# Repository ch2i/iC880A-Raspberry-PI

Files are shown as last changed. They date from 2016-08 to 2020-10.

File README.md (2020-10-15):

# Raspberry PI iC880A and LinkLab Lora Gateway Shield

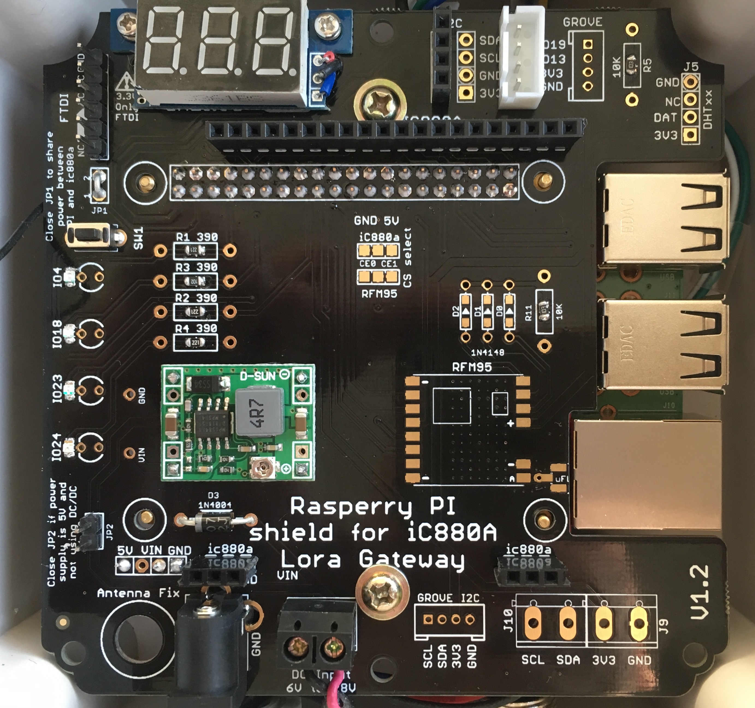
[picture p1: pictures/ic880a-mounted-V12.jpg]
     

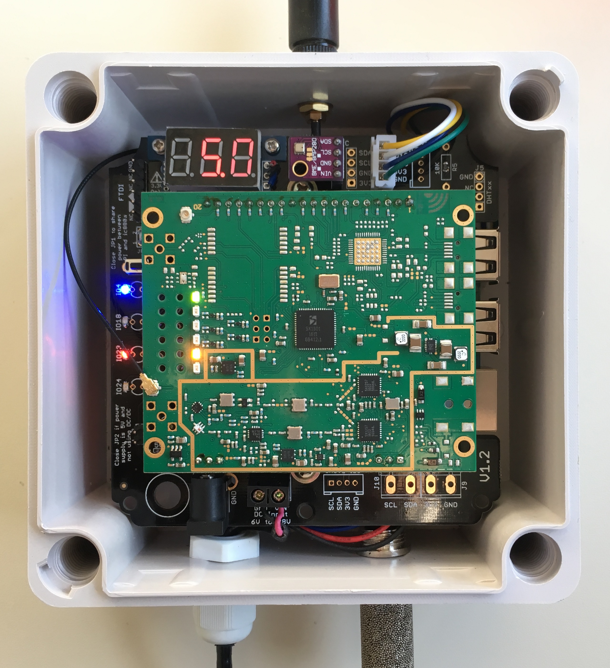
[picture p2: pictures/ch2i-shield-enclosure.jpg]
     

At the begining this shield has been created to help wiring between Raspberry PI and ISMT [iC880A][10] LoraWan concentrator Gateway (SPI version) and to be able to put the whole thing into a outdoor enclosure such as this [one][15].

Then I decided to add some funky stuff like:

**New in V1.2** (tested, working fine)

 - Added push button on GPIO19 to be able to shutdown PI Locally (if you don't use RFM95 with IRQ) 
 - Reversed DHT connector [#4][4]
 - Added FTDI connector to be able to take hand on PI console when in enclosure (lost network or whatever, no more need to get all off the enclosure and connect HDMI cable to see what's going on)
 - Added footprint for excellent Murata OKI-78SR-5 DC/DC 5V
 - Fixed Mini Voltmeter Holes Spacing

**Still V1.1** 

- Footprint for [iC880a][10] ISMT LoraWan concentrator (main goal)
- ~~Can be also used between LinkLabs [board][11] and Raspi~~
- I2C and Grove connectors to be able to add internal/external sensors such as BME280, SI7021 or HTU21D
- Footprint for DC/DC step down if you want to do some simple [POE splitter][16] to power the whole thing thru a network cable or any power 
- Footprint for a simple Lora module such as RFM95 that can be used a Single Channel Gateway or also act as a Lora Node
- Power with DC Barrel connector and terminal block
- Four visual GPIO Led
- Footprint for DHT1x Temperature/Humidity sensors
- Easy to build and solder, 0805 or PTH components
- Holes to fix board on enclosure or other support

# Detailed Description

No specific documentation for now, it's just a kind of wiring helper, please see Gateway section on [TTN Wiki][13] and also on [TTN Forums][14] for more information on these gateways.

You can power the board with 5V going to Raspberry PI USB power directly, in this case use a descent power supply.
You can also use "basic" POE with injector and splitter, this is what I do to oustide (I inject 12V) and use the DC Barrel, in this case I put D4 and a DC/DC Step down calibrated to 5V (**do calibration before beforre pluging any boards/devices because default DC/DC output can be over 5V can fry all your boards**)

If you need to use sensors you can check out these [examples][12], they're just awesome, I'll post examples as soon as I get all working.

If you use linklabs board you can use these [version][2] of packet_forwarder, it has been modified to drive LED of linklabs boards and PPS modem line.

# Installation

No specific documentation for now, it's just a kind of wiring helper, please see Gateway section on [TTN Wiki][13] and Installation is quite easy but as the plate need to go over RPI network and USB connector, you need to use a 2x20 Raspberry PI connector such as [this one][25] form adafruit. You can also find some on ebay.

See generic SX1031 Lora Gateway setup for software [installation](https://github.com/ch2i/LoraGW-Setup)

# Schematic

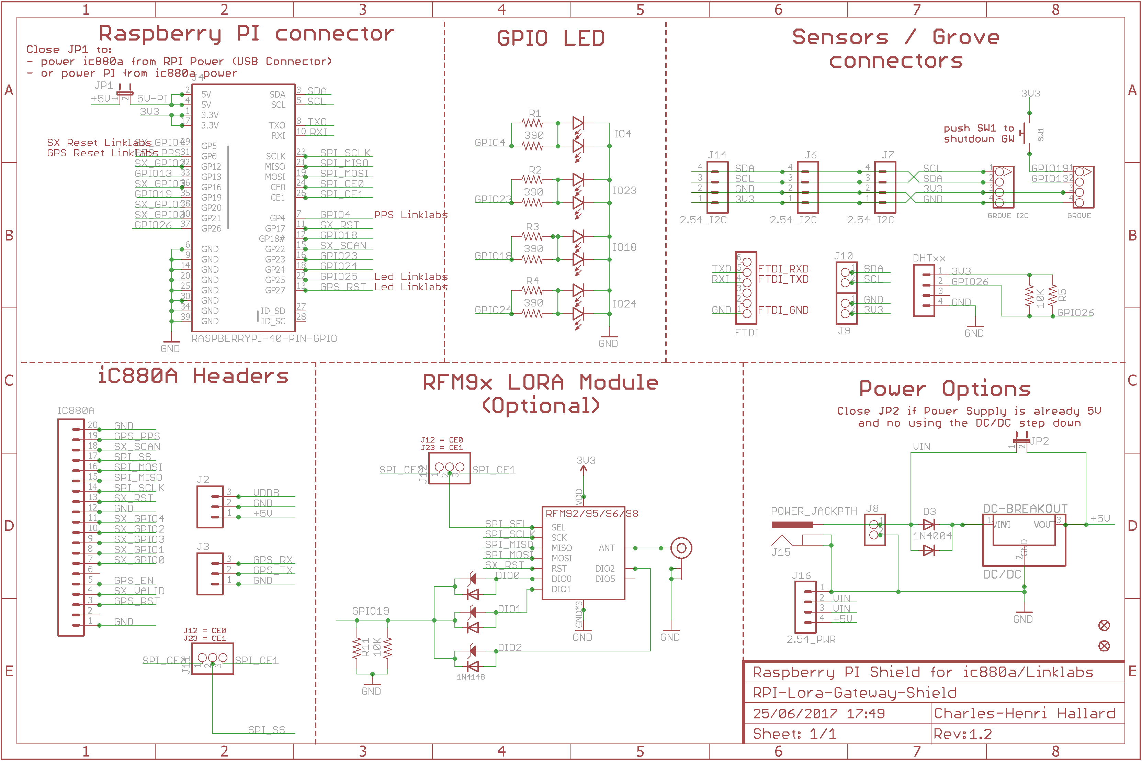
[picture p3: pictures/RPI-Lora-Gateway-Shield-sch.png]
schematic
  

# Boards 

**Top side**
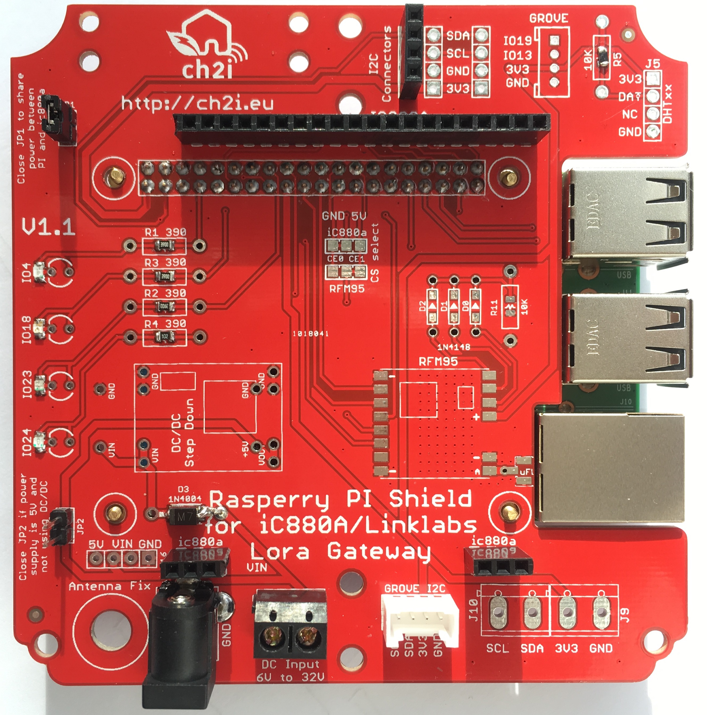
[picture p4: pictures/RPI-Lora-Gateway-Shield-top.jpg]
    

**Bottom side**
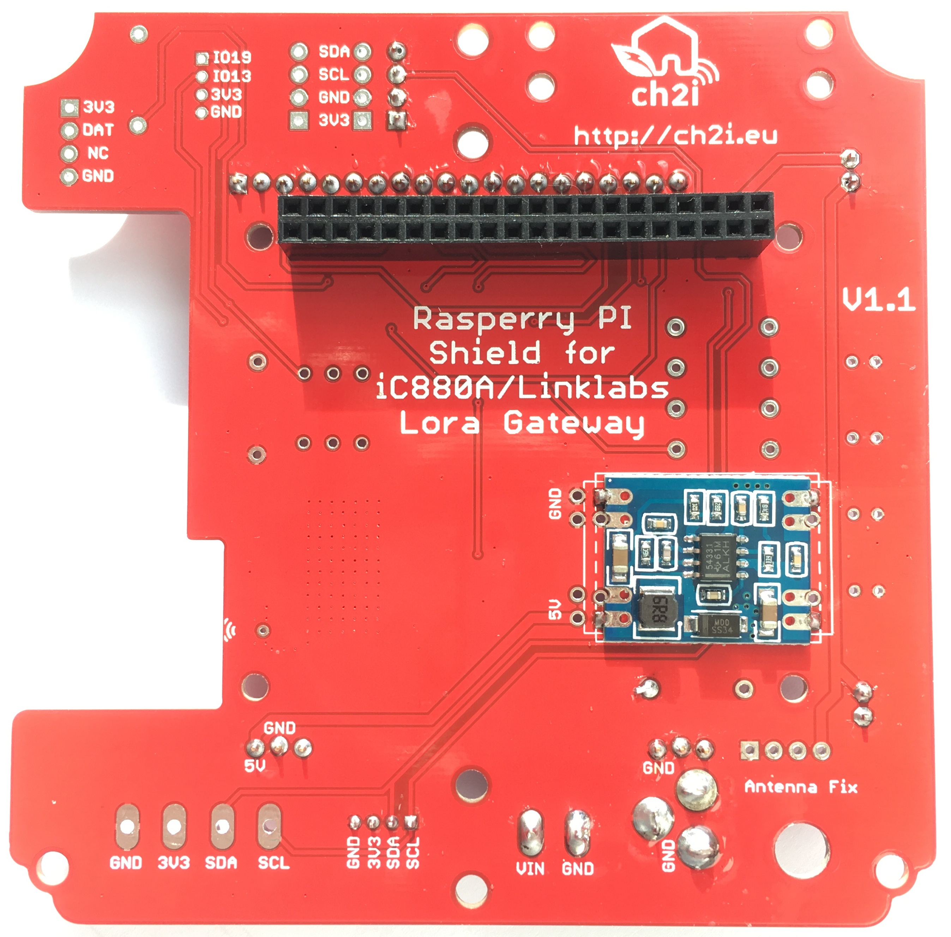
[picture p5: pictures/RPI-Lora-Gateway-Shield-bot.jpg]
    

You can order the PCB of this board on my [tindie store](https://www.tindie.com/products/hallard/ic880a-lora-concentrator-shield-raspberry-pi/) located in EU or at [PCBs.io][3] (not sure PCBs.io still alive). Don't worry they still have a bug with top/bottom thumbails view but final boards are okay
PCBs.io give me some reward when you order my designed boards from their site. This is pretty good, because I can use these rewards to create and design new boards and order boards for a discounted price, so if you don't care about PCB manufacturer please use PCBs.io.

[](https://www.tindie.com/products/hallard/ic880a-lora-concentrator-shield-raspberry-pi/)

## Assembled boards into nice enclosure with sensors

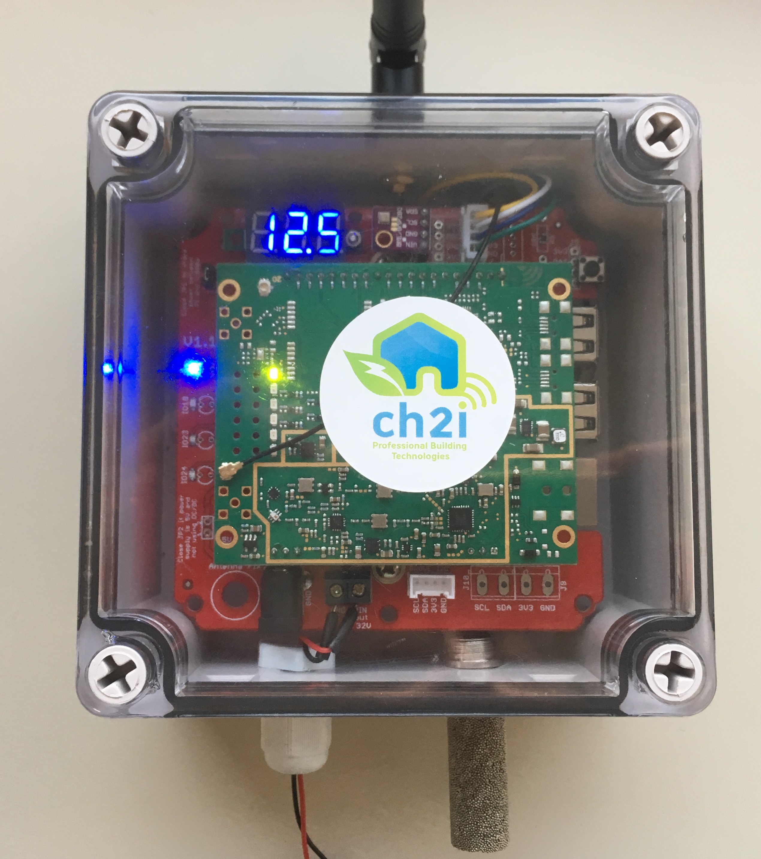
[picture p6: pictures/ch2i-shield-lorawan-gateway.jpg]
Fully assembled and in nice enclosure with sensors
     

Sensors values en Cayenne (see [installer][26] readme for setup)
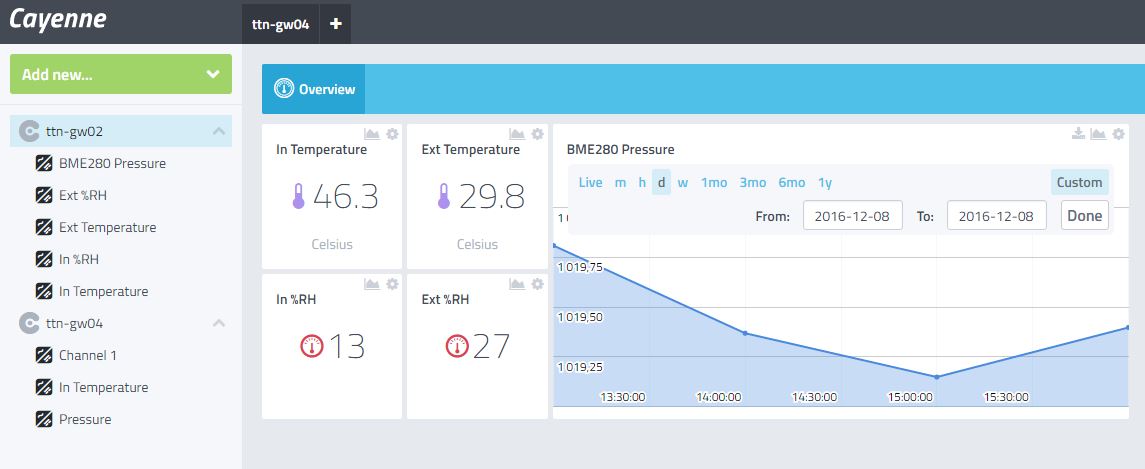
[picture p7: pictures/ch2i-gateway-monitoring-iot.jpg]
Gateway Monitoring with external sensors
     

## Bill Of Material

Nothing fancy, all components are 0805 and/or PTH and can be ordered almost anywhere (digikey, mouser, radiospare, ...). 
use only what you need dependings on what you want to do. 

- ~~Adjustable DC/DC step down like this [one][18] or this [one][19]~~
- Fixed 5V DC/DC step down like this 3A [one][27] or this 1.5A [one][28] or excellent Murata [OKI-78SR-5][44]
- LED for 4 GPIO (4/23/18/24) are 3mm PTH or 0805, color of your choice
- If you use RFM95, diode for DIO0/DIO1/DIO2 (if you want to use interrupts) are 1N4148 PTH or SOD123
- POE Splitter such as [these][16] and POE injector as this [one][17]
- Terminal blocks are 5MM spacing
- D3 is 1N400x (1N4001, 1N4007, ..) whatever you have, PTH or DO214
- DC/Barell power jack 
- Grove connector and others at [seeedstudio][20]
- ~~Some PI connector with [long pins][21] for pluging this board and Linklabs one~~
- Some 2X20 pins [PI connector][29] for pluging this board  
- Antenna [UFL][22] with [IPEX][23] cable or [SMA][24] if using Lora Module
- Small Enclosure 125x125mm 75mm Height [#1][40] or [#2][41]
- optional [Outdoor protection sleeve][42] for SI7021/HTU21D
- optional [Breakout][43] for enclosure temperature monitoring BME280
- optional tactile switch like this [one][46] or for external on enclosure this [one][47] (connect button LED to Heatbeat LED (GPIO4)
- optional digital [voltmeter][48] to display input voltage
- 2 x [M4 Hex Brass Spacer Standoff][44] to fix board on enclosure, (higher give you more space below to put POE splitter for example) 25mm to 35mm is fine

# License

   

This work is licensed under a [Creative Commons Attribution-NonCommercial 4.0 International License](http://creativecommons.org/licenses/by-nc/4.0/)    
If you want to do commercial stuff with this project, please contact [CH2i company](https://www.ch2i.eu/en#support) so we can organize an simple agreement.

# Misc

See news and other projects on my [blog][1] 
 
[1]: https://hallard.me
[2]: https://github.com/ch2i/packet_forwarder
[3]: https://PCBs.io/share/rmVdD
[4]: https://github.com/ch2i/iC880A-Raspberry-PI/issues/4

[10]: http://webshop.imst.de/ic880a-spi-lorawan-concentrator-868mhz.html
[11]: http://forum.thethingsnetwork.org/t/raspberry-pi-lorawan-gateway-board/1071
[12]: https://github.com/leon-anavi/rpi-examples
[13]: https://staging.thethingsnetwork.org/wiki/Hardware/Gateways/Overview
[14]: http://forum.thethingsnetwork.org/c/gateways
[15]: https://www.aerial.net/shop/product_info.php?products_id=1102
[16]: https://www.aerial.net/shop/index.php?cPath=22_124
[17]: http://wiki.dragino.com/index.php?title=PoE_Injector
[18]: http://www.ebay.com/itm/2-PCS-MP1584EN-Step-down-Power-DC-DC-3A-Adjustable-Ultra-LM2596-Step-down-Module-/301798394307
[19]: http://www.ebay.com/itm/1x-Tiny-4-5-28V-3A-DC-DC-Buck-Converter-Step-down-Power-Regulator-MP1584EN-/141524007951
[20]: http://www.seeedstudio.com/depot/index.php?main_page=opl_info&opl_id=4
[21]: http://www.ebay.com/itm/170578495165
[22]: http://www.ebay.com/itm/351690376555
[23]: http://www.ebay.com/itm/351738196013
[24]: http://www.ebay.com/itm/371534934746

[25]: https://www.adafruit.com/products/1979
[26]: https://github.com/ch2i/ic880a-gateway/tree/ch2i-rpi-shield

[27]: http://www.ebay.com/itm/121929386506?var=420920026758
[28]: http://www.ebay.com/itm/371348168950
[29]: http://www.ebay.com/itm/351588181858

[30]: https://github.com/ch2i/packet_forwarder/blob/master/poly_pkt_fwd/readme.md

[40]: http://www.ebay.com/itm/262500056078
[41]: http://www.aliexpress.com/item/Free-Shipping-Good-Quality-ABS-Material-Transparent-Cover-IP66-Waterproof-Electrical-Switch-Box-125-125-75mm/32522255056.html
[42]: http://www.aliexpress.com/item/Temperature-and-humidity-Protective-sleeve-Accessories-PCB-for-SHT20-SHT21-SHT25/32695663191.html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
[43]: http://www.ebay.com/itm/401000227934
[44]: http://www.ebay.com/itm/182181715511?var=483966356069
[45]: http://www2.mouser.com/ProductDetail/Murata-Power-Solutions/OKI-78SR-5-15-W36H-C/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
[46]: http://www.ebay.com/itm/391462862706
[47]: http://www.ebay.com/itm/232153789354?var=531358445664
[48]: http://www.ebay.com/itm/301856945402

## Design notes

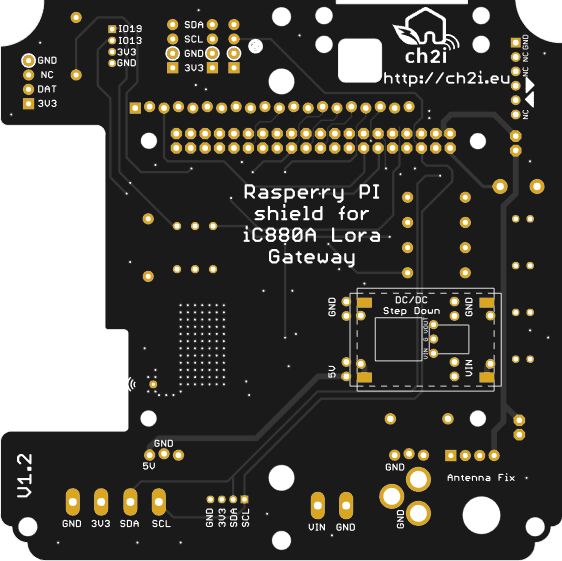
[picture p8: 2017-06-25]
pictures/RPI-Lora-Gateway-Shield-bot.png

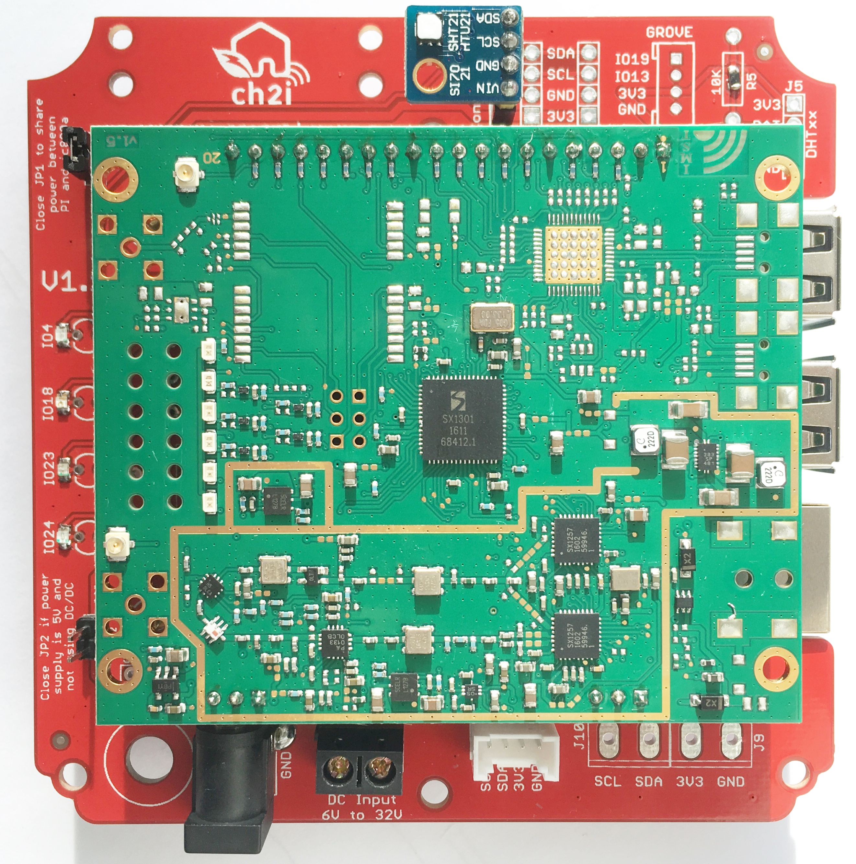
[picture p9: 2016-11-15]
pictures/RPI-Lora-Gateway-mounted.jpg

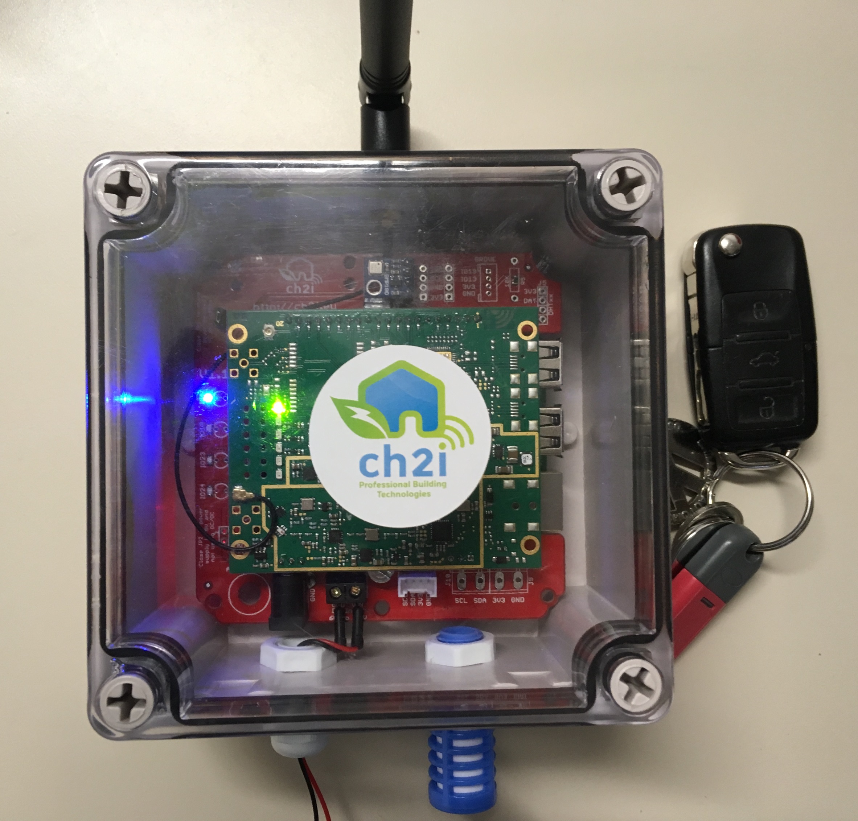
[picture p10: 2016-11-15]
pictures/iC880A-mounted-enclosure.jpg

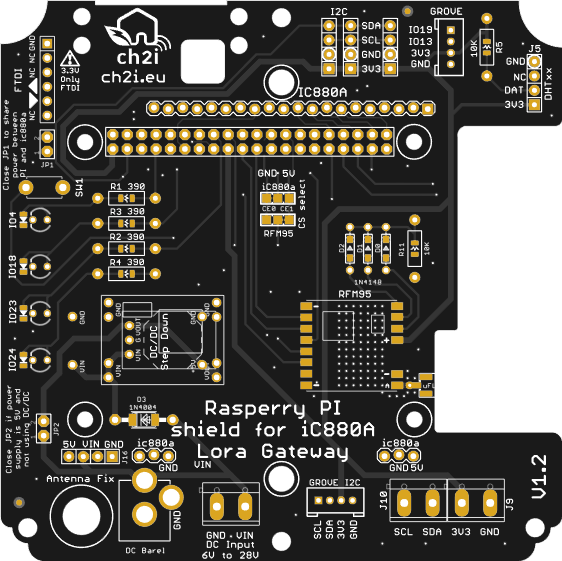
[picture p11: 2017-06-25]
pictures/RPI-Lora-Gateway-Shield-top.png

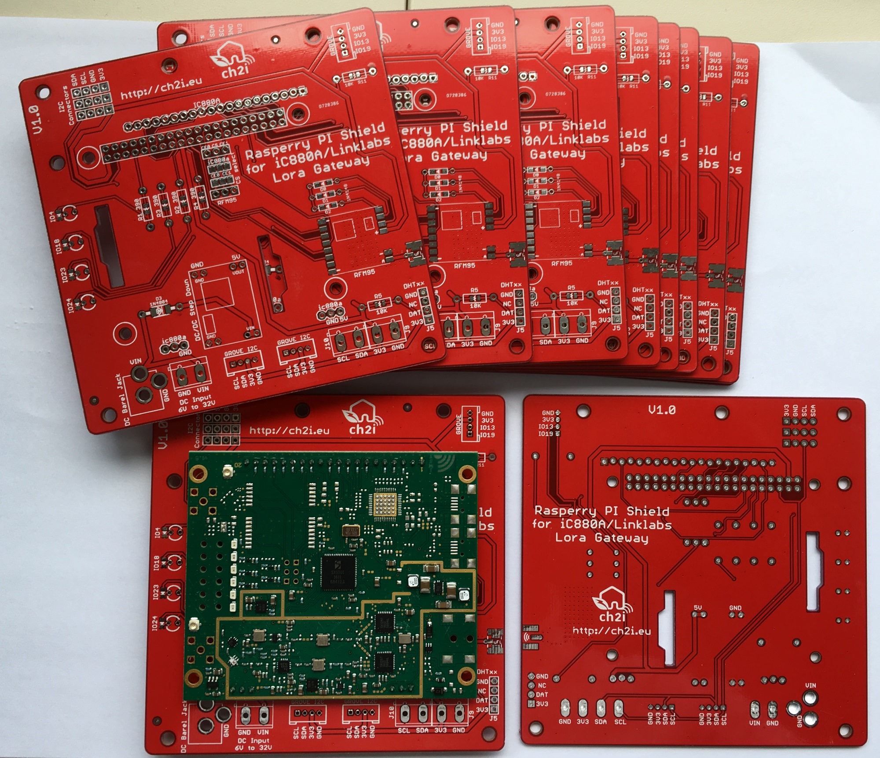
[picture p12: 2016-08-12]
pictures/RPI-Lora-Gateway-PCB.jpg

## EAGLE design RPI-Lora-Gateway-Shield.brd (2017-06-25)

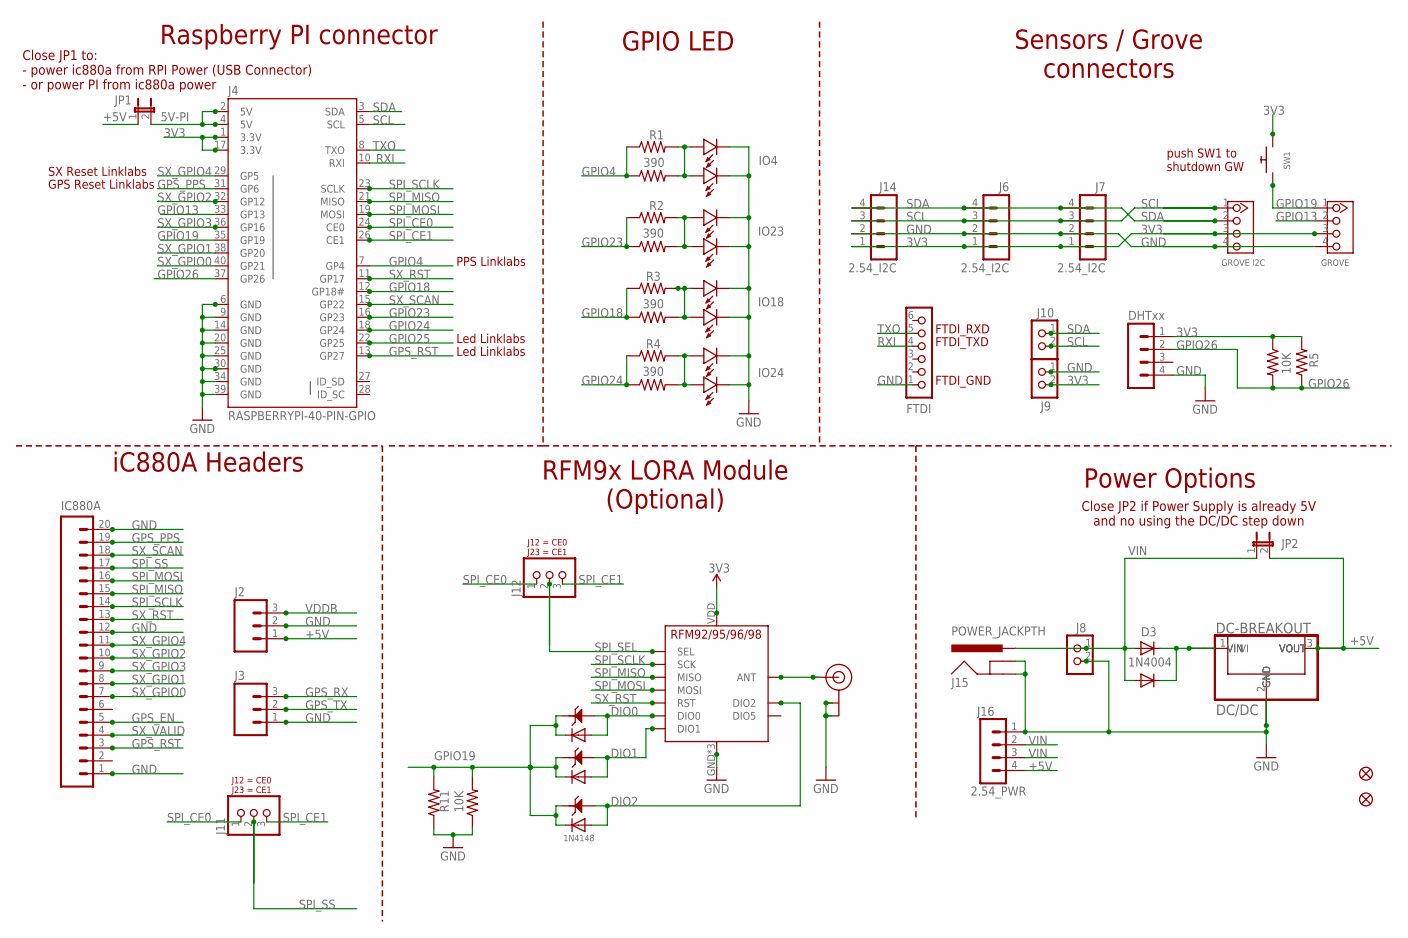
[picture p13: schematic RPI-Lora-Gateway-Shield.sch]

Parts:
D0, D1, D2: 1N4148; SOD123-2.7X1.6
D3: 1N4004; DO41-10
D4: 1N4007; DO-214AC
D5: 1N4148; DO-1N4148
D6, D7: DIODEDO-1N4148; DO-1N4148
DC/DC: DC-BREAKOUT
FID2, FID3: FIDUCIAL""; FIDUCIAL_1MM
FTDI: CON_HEADER_1X06-PTH; M1X6
IC880A: M20LOCK; 1X20_LOCK
J1: GROVE; HW4-2.0
J2, J3: M03LOCK; 1X03_LOCK
J4: RASPBERRYPI-40-PIN-GPIO; 2X20-SHROUDED
J5: DHTxx; 1X04_NO_LOCK
J6, J7, J14: 2.54_I2C; 1X04_NO_LOCK
J8, J9, J10: CON_TERMINAL_BLOCK_02-5MM; TERMINAL_BLOCK_2P_5
J11, J12: JUMPER_1X30805; JP3_0805
J13: GROVE I2C; HW4-2.0
J15: POWER_JACKPTH; POWER_JACK_PTH
J16: 2.54_PWR; 1X04_NO_LOCK
JP1, JP2: JUMPER2
LED1, LED2, LED3, LED4: LED0805; 0805-LED
R1, R2, R3, R4: 390; AXIAL-0.4
R5, R11: 10K; AXIAL-0.4
R6, R7, R8, R9, R10, R12: RESISTOR0805-RES; 0805-RES
SW1: SWITCH_PUSHBUTTONEVQ-PE; TACT_PANA-EVQ
U$2: RFM95
U$3: ANTENNA-UFL; UFL_PAD
U$4: IO4; LED3MM
U$5: IO23; LED3MM
U$6: IO18; LED3MM
U$7: IO24; LED3MM
U$8: DC-BREAKOUTFIXED; DC-DC-FIXED
U$11: OKI-78SR; OKI-78SRH

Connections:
3V3: J1.3, J4.1 (3.3V), J4.17 (3.3V), J5.1, J6.1, J7.1, J9.2, J13.3, J14.1, R5.P$1 (1), R10.2, SW1.P$2, U$2.VDD (VCC)
5V-PI: J4.2 (5V), J4.4 (5V), JP1.2
+5V: DC/DC.VOUT-1 (VOUT), DC/DC.VOUT-2 (VOUT), J2.1, J16.4, JP1.1, JP2.2, U$8.VOUT-1 (VOUT), U$8.VOUT-2 (VOUT), U$11.3 (VO)
DIO0: D0.1, D6.A, U$2.DIO0
DIO1: D1.1, D7.A, U$2.DIO1
DIO2: D2.1, D5.A, U$2.DIO2
GND: DC/DC.GND-1 (GND), DC/DC.GND-2 (GND), DC/DC.GND-3 (GND), DC/DC.GND-4 (GND), FTDI.1, IC880A.1, IC880A.12, IC880A.20, J1.4, J2.2, J3.1, J4.6 (GND), J4.9 (GND), J4.14 (GND), J4.20 (GND), J4.25 (GND), J4.30 (GND), J4.34 (GND), J4.39 (GND), J5.4, J6.2, J7.2, J8.2, J9.1, J13.4, J14.2, J15.GND, J15.GNDBREAK, J16.1, LED1.MINUS, LED2.MINUS, LED3.MINUS, LED4.MINUS, R11.P$1 (1), R12.1, U$2.GND, U$2.GND1 (GND), U$2.GND2 (GND), U$3.GND1 (GND), U$3.GND2 (GND), U$4.MINUS, U$5.MINUS, U$6.MINUS, U$7.MINUS, U$8.GND-1 (GND), U$8.GND-2 (GND), U$8.GND-3 (GND), U$8.GND-4 (GND), U$11.2 (GND)
GPIO4: J4.7 (GP4), R1.P$1 (1), R6.1
GPIO13: J1.2, J4.33 (GP13)
GPIO18: J4.12 (GP18#), R3.P$1 (1), R8.1
GPIO19: D0.2, D1.2, D2.2, D5.C, D6.C, D7.C, J1.1, J4.35 (GP19), R11.P$2 (2), R12.2, SW1.P$1
GPIO23: J4.16 (GP23), R2.P$1 (1), R7.1
GPIO24: J4.18 (GP24), R4.P$1 (1), R9.1
GPIO25: J4.22 (GP25)
GPIO26: J4.37 (GP26), J5.2, R5.P$2 (2), R10.1
GPS_EN: IC880A.5
GPS_PPS: IC880A.19, J4.31 (GP6)
GPS_RST: IC880A.3, J4.13 (GP27)
GPS_RX: J3.3
GPS_TX: J3.2
unnamed: D3.C, D4.1 (C), DC/DC.VIN-1 (VIN), DC/DC.VIN-2 (VIN), U$8.VIN-1 (VIN), U$8.VIN-2 (VIN), U$11.1 (VI)
unnamed: LED4.PLUS, R4.P$2 (2), R9.2, U$7.PLUS
unnamed: LED1.PLUS, R1.P$2 (2), R6.2, U$4.PLUS
unnamed: LED2.PLUS, R2.P$2 (2), R7.2, U$5.PLUS
unnamed: LED3.PLUS, R3.P$2 (2), R8.2, U$6.PLUS
unnamed: U$2.ANT, U$3.ANT1 (SIGNAL), U$3.ANT2 (SIGNAL)
RXI: FTDI.4, J4.10 (RXI)
SCL: J4.5 (SCL), J6.3, J7.3, J10.2, J13.1, J14.3
SDA: J4.3 (SDA), J6.4, J7.4, J10.1, J13.2, J14.4
SPI_CE0: J4.24 (CE0), J11.1, J12.1
SPI_CE1: J4.26 (CE1), J11.3, J12.3
SPI_MISO: IC880A.15, J4.21 (MISO), U$2.MISO
SPI_MOSI: IC880A.16, J4.19 (MOSI), U$2.MOSI
SPI_SCLK: IC880A.14, J4.23 (SCLK), U$2.SCK
SPI_SEL: J12.2, U$2.NSS (SEL)
SPI_SS: IC880A.17, J11.2
SX_GPIO0: IC880A.7, J4.40 (GP21)
SX_GPIO1: IC880A.8, J4.38 (GP20)
SX_GPIO2: IC880A.10, J4.32 (GP12)
SX_GPIO3: IC880A.9, J4.36 (GP16)
SX_GPIO4: IC880A.11, J4.29 (GP5)
SX_RST: IC880A.13, J4.11 (GP17), U$2.RST
SX_SCAN: IC880A.18, J4.15 (GP22)
SX_VALID: IC880A.4
TXO: FTDI.5, J4.8 (TXO)
VDDB: J2.3
VIN: D3.A, D4.2 (A), J8.1, J15.PWR, J16.2, J16.3, JP2.1

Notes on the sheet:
PPS Linklabs
SX Reset Linklabs
GPS Reset Linklabs
Led Linklabs
iC880A Headers
RFM9x LORA Module (Optional)
Power Options
Raspberry PI connector
GPIO LED
Sensors / Grove connectors
Close JP2 if Power Supply is already 5V and no using the DC/DC step down
Close JP1 to: - power ic880a from RPI Power (USB Connector) - or power PI from ic880a power
FTDI_RXD
FTDI_TXD
FTDI_GND
push SW1 to shutdown GW

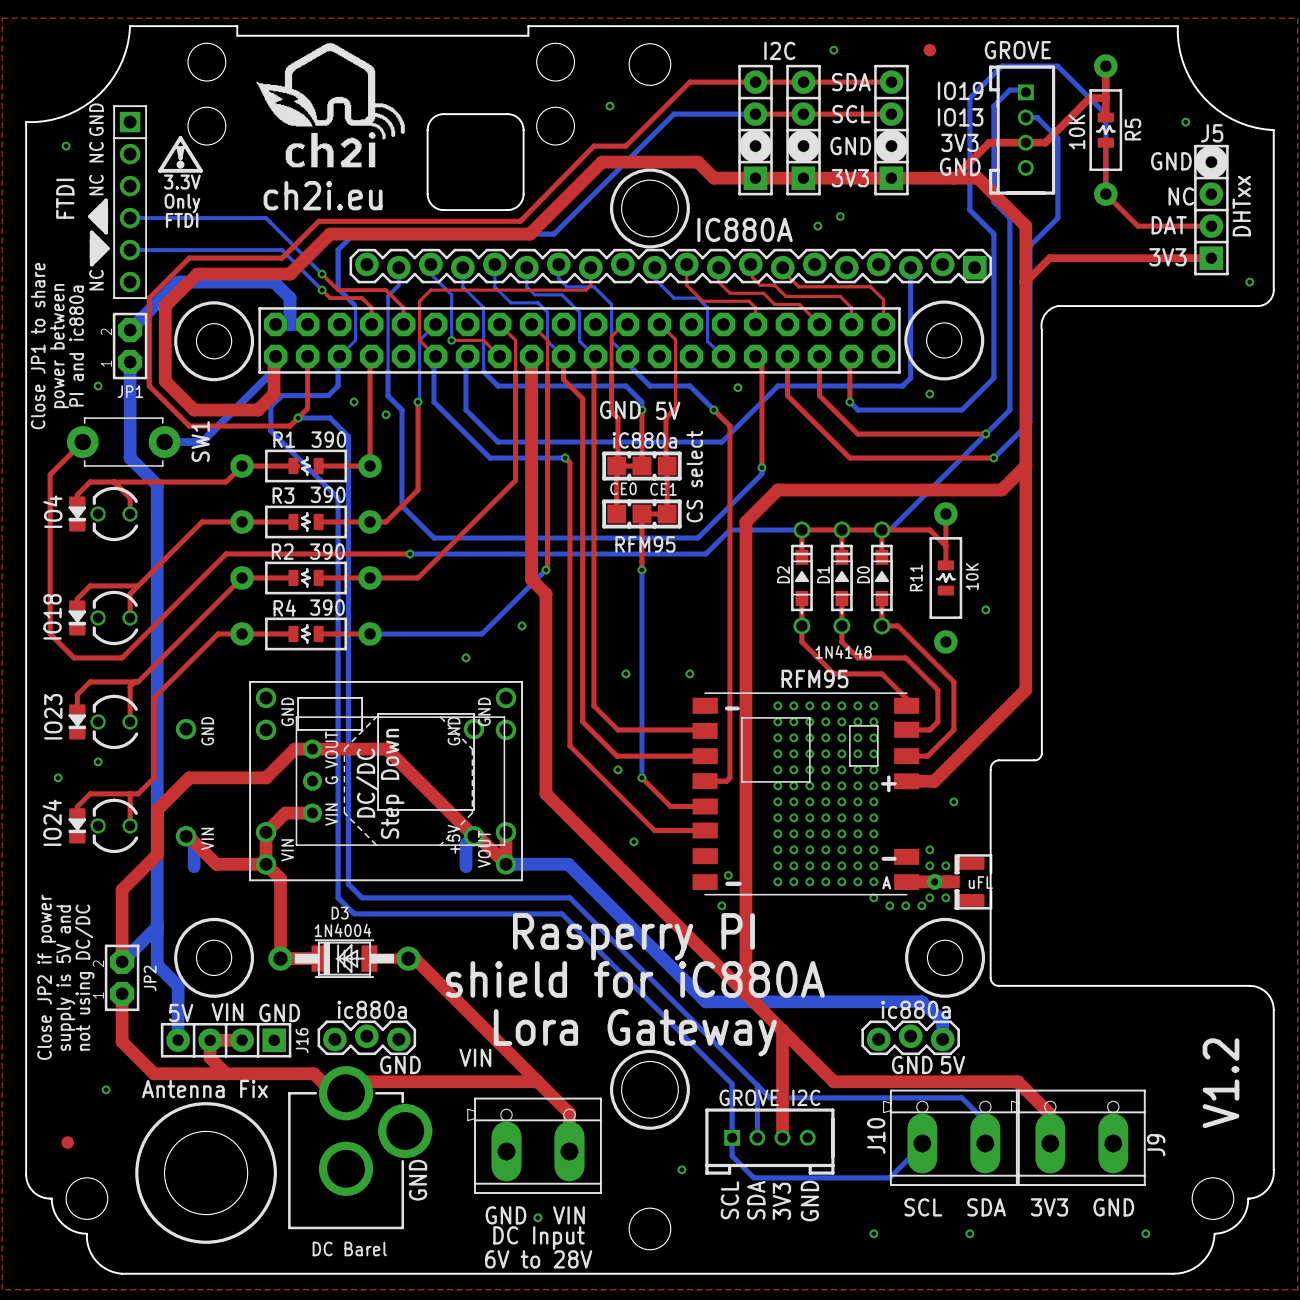
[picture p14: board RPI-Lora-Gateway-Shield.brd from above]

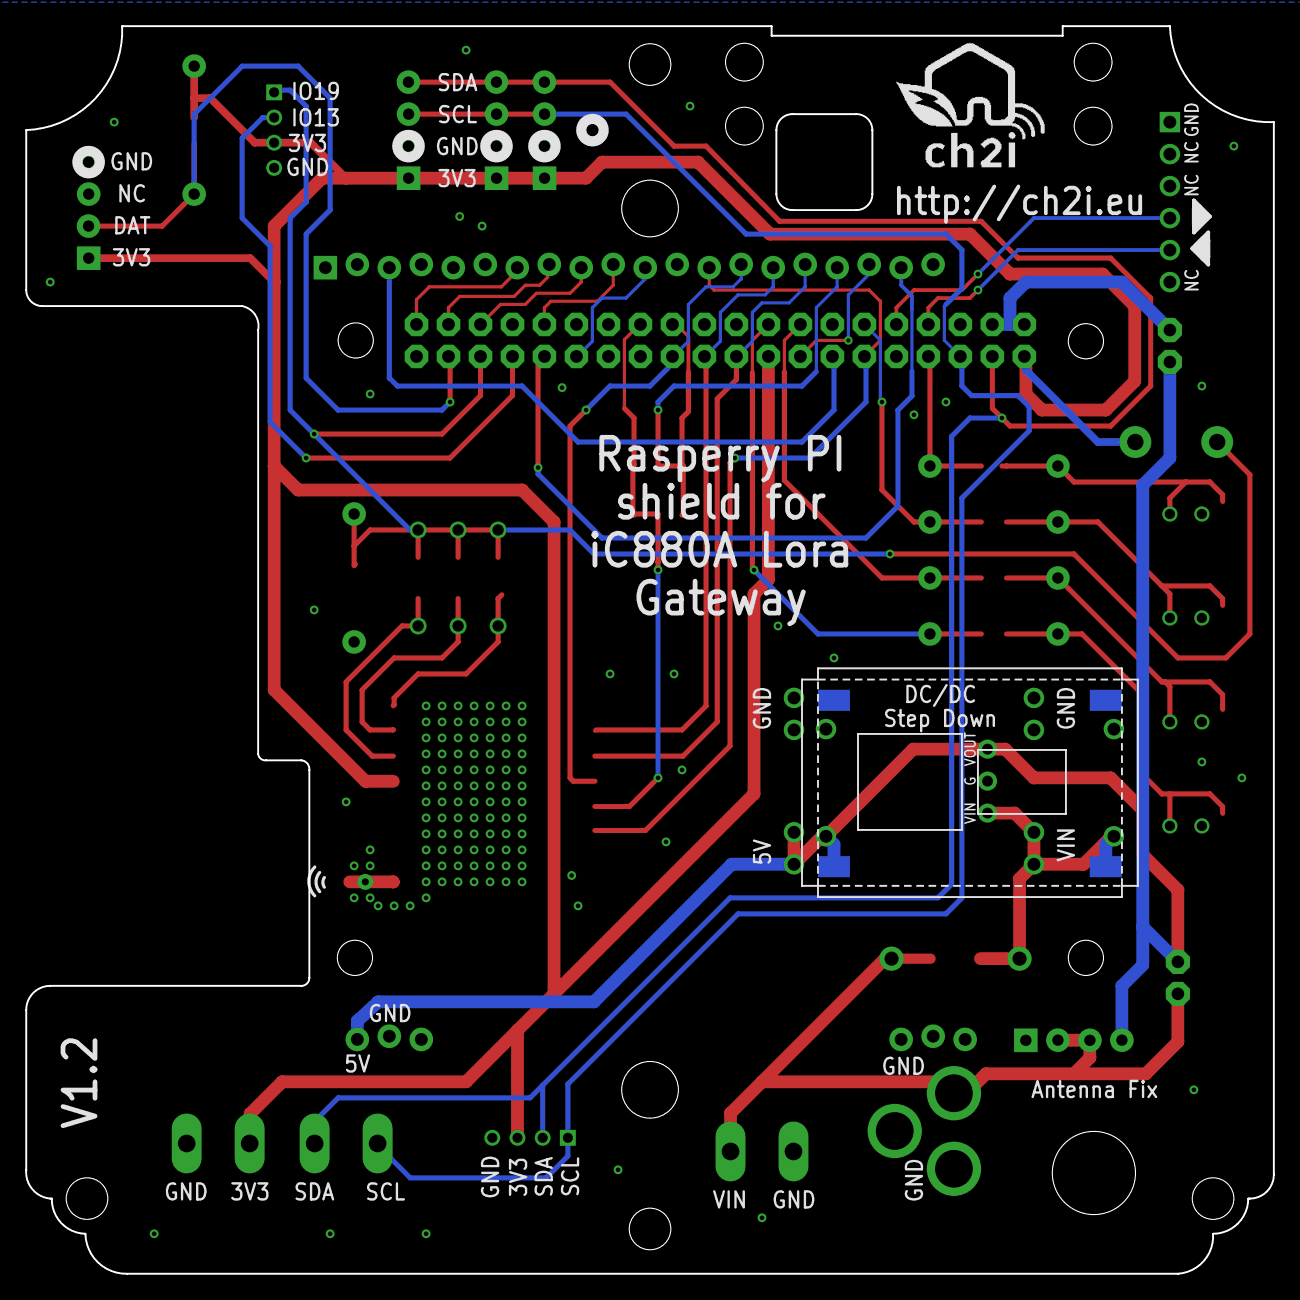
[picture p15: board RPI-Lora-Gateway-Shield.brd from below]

Board: 2 copper layers, 99.1 x 99.1 mm, 62 parts (2 on the bottom side), 41 nets.

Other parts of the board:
H1, H2, H3, H4: STAND-OFF
U$1, U$9: LOGO_CH2I_110MM

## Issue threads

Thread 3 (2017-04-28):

DC/DC step down 3A link

atoy40, 2017-04-28:
Hello,

the first link for the 3A step down point to a fixed 3.3V version.

Anthony.

hallard, 2017-06-25:
Hello,
Thanks for pointing it out, it's now corrected

Closed 2017-06-25.

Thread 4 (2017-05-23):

DHT 22 header rotation needed

pjb304, 2017-05-23:
The DHT header needs to be rotated 180 degrees so that when soldered on it does not clash with the ic880a PCB.  At the moment it has to be soldered on at an angle.

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

hallard, 2017-06-25:
Hi,
Thanks for pointing up
It's now corrected on V1.2 with also some new features

Closed 2017-06-25.

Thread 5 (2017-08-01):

Using the board with RFM95 as a single channel gateway

niau, 2017-08-01:
So I tried to follow the soldering instructions:

Unfortunately i was unable to make the single chan gw working.

Some outputs:

```
pi@ttn-gateway:~/single_chan_pkt_fwd $ gpio readall
 +-----+-----+---------+------+---+---Pi 3---+---+------+---------+-----+-----+
 | BCM | wPi |   Name  | Mode | V | Physical | V | Mode | Name    | wPi | BCM |
 +-----+-----+---------+------+---+----++----+---+------+---------+-----+-----+
 |     |     |    3.3v |      |   |  1 || 2  |   |      | 5v      |     |     |
 |   2 |   8 |   SDA.1 |  OUT | 1 |  3 || 4  |   |      | 5v      |     |     |
 |   3 |   9 |   SCL.1 |   IN | 1 |  5 || 6  |   |      | 0v      |     |     |
 |   4 |   7 | GPIO. 7 |   IN | 1 |  7 || 8  | 0 | IN   | TxD     | 15  | 14  |
 |     |     |      0v |      |   |  9 || 10 | 1 | IN   | RxD     | 16  | 15  |
 |  17 |   0 | GPIO. 0 |  OUT | 1 | 11 || 12 | 0 | IN   | GPIO. 1 | 1   | 18  |
 |  27 |   2 | GPIO. 2 |   IN | 0 | 13 || 14 |   |      | 0v      |     |     |
 |  22 |   3 | GPIO. 3 |  OUT | 1 | 15 || 16 | 0 | OUT  | GPIO. 4 | 4   | 23  |
 |     |     |    3.3v |      |   | 17 || 18 | 0 | IN   | GPIO. 5 | 5   | 24  |
 |  10 |  12 |    MOSI |   IN | 0 | 19 || 20 |   |      | 0v      |     |     |
 |   9 |  13 |    MISO |   IN | 0 | 21 || 22 | 0 | IN   | GPIO. 6 | 6   | 25  |
 |  11 |  14 |    SCLK |   IN | 0 | 23 || 24 | 1 | IN   | CE0     | 10  | 8   |
 |     |     |      0v |      |   | 25 || 26 | 1 | IN   | CE1     | 11  | 7   |
 |   0 |  30 |   SDA.0 |   IN | 1 | 27 || 28 | 1 | IN   | SCL.0   | 31  | 1   |
 |   5 |  21 | GPIO.21 |   IN | 1 | 29 || 30 |   |      | 0v      |     |     |
 |   6 |  22 | GPIO.22 |  OUT | 1 | 31 || 32 | 0 | IN   | GPIO.26 | 26  | 12  |
 |  13 |  23 | GPIO.23 |   IN | 0 | 33 || 34 |   |      | 0v      |     |     |
 |  19 |  24 | GPIO.24 |   IN | 0 | 35 || 36 | 0 | IN   | GPIO.27 | 27  | 16  |
 |  26 |  25 | GPIO.25 |  OUT | 1 | 37 || 38 | 0 | IN   | GPIO.28 | 28  | 20  |
 |     |     |      0v |      |   | 39 || 40 | 0 | IN   | GPIO.29 | 29  | 21  |
 +-----+-----+---------+------+---+----++----+---+------+---------+-----+-----+
 | BCM | wPi |   Name  | Mode | V | Physical | V | Mode | Name    | wPi | BCM |
 +-----+-----+---------+------+---+---Pi 3---+---+------+---------+-----+-----+
```
```
pi@ttn-gateway:~/RadioHead/examples/raspi/spi_scan $ sudo ./spi_scan
Checking register(0x42) with CS=GPIO06 => Nothing!
Checking register(0x10) with CS=GPIO06 => Nothing!
Checking register(0x42) with CS=GPIO07 => SX1276 RF95/96 (V=0x12)
Checking register(0x10) with CS=GPIO07 => Nothing!
Checking register(0x42) with CS=GPIO08 => Nothing!
Checking register(0x10) with CS=GPIO08 => Nothing!
Checking register(0x42) with CS=GPIO26 => Nothing!
Checking register(0x10) with CS=GPIO26 => Nothing!
```

```
pi@ttn-gateway:~/ic880a-gateway/src/check_ic880a $ sudo ./check_ic880a

-- Asserting CS=GPIO8 (CE0) --
Checking SX1301 register(0x01) => Nothing!
Checking SX1257 register(0x07) => Nothing!
Checking SX1255 register(0x07) => Nothing!
Checking RFM9x  register(0x42) => Nothing!
Checking RFM69  register(0x10) => Nothing!

-- Asserting CS=GPIO7 (CE1) --
Checking SX1301 register(0x01) => Unknown (V=0x09)
Checking SX1257 register(0x07) => Unknown (V=0x80)
Checking SX1255 register(0x07) => Unknown (V=0x80)
Checking RFM9x  register(0x42) => SX1276 RF95/96 (V=0x12)
Checking RFM69  register(0x10) => Nothing!
```

Failures start here:
```
pi@ttn-gateway:~/RadioHead/examples/raspi/rf95 $ sudo ./rf95_client
rf95_client

RF95 module init failed, Please verify wiring/module
RF95 CS=GPIO8, IRQ=GPIO19, LED=GPIO24
rf95_client Ending
````

Also tried various nss, rst and dio setting for the global_config.json none worked.

hallard, 2017-08-03:
@niau
So you're using this board with an RFM95 connected correct?
This repo is for the PCB board, there is no code here, so I'm trying to guess what code are you using and where it come from?

But neither mind, I think I got it, code results indicate that RFM95 is detected on CS pin connected to CE1, that's fine ;-)
but your client rf95_client try to talk with it on CS=GPIO8 so that's why it's not working, you need to adjust rfm95_client to use GPIO7 (CE1) and not GPIO8, that should make it works.

niau, 2017-08-03:
https://github.com/hallard/single_chan_pkt_fwd

niau, 2017-08-03:
So to explain a bit the rf95_client and servers got fixed by your suggestion (man I shoulda see that :)

#define RF_LED_PIN RPI_V2_GPIO_P1_18 // Led on GPIO24 so P1 connector pin #18
//#define RF_CS_PIN  RPI_V2_GPIO_P1_24 // Slave Select on CE0 so P1 connector pin #24
#define RF_CS_PIN  RPI_V2_GPIO_P1_26 // Slave Select on CE0 so P1 connector pin #26
#define RF_IRQ_PIN RPI_V2_GPIO_P1_35 // IRQ on GPIO19 so P1 connector pin #35

niau, 2017-08-03:
@hallard  thanks for your help single channel gateway now works ;)

Closed 2017-08-03.

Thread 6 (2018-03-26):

GPS connection for iC880A

Octoate, 2018-03-26:
Hi,
thanks for your great work with the backplane. It is very versatile and great to use!
However, I am missing one feature: The support for a GPS module with PPS signal. It would be great if you can add a header for a GPS module (e.g. for a GN-801 GPS module) that connects the UART to the Raspberry Pi and the PPS pin of the module to pin 19 of the IMST iC880A. Currently I am modifying the board by myself, but it would be great if I can just add a header and connect the GPS module there.
I know there has been a discussion about the sense of this addon, but the GPS module is very cheap so why not adding it :-)?

Best regards,
Tim

Octoate, 2018-03-28:
Well, I guess it would make sense to use a GPS sensor that is widely available, so I wouldn't recommend the one, I am using here (and it doesn't have a pin header anyway ;-)). Maybe the pin header for the NEO6MV2 would be nice like on this boards:

https://www.ebay.com/itm/GY-NEO6MV2-NEO-6M-GPS-Module-Board-with-Antenna-for-Arduino-Raspberry-Pi/142660988559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

or, because it has a good availability, the one of the Adafruit Ultimate GPS:

https://www.adafruit.com/product/746

What do you think?

hallard, 2019-06-13:
I'm using this [one](https://www.electrodragon.com/product/gnss-module-atgm336h/) on my [RAK831 PI Zero Board](https://github.com/hallard/RAK831-Zero) Would it be okay for you ?

Another Idea would be using an USB One, unfortunately both same pinout execpt TX/RX reverser
https://www.electrodragon.com/product/neo-6m-gps-module-r2/

Closed 2019-06-13.

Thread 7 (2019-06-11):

All parts optional?

Donderda, 2019-06-11:
Do I need parts (except the connectors) if I just want to use it as connection between the rpi and the ic880a?

hallard, 2019-06-13:
Nope,
You can use only the connectors, but don't forget to close JP1 to power the iC880A from RPI Power

Closed 2019-06-13.

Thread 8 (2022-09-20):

Doesn't work with newer PIs

marcelstoer, 2022-09-20:
Maybe a note to the README that it won't work with newer PIs as they moved the Ethernet connector? Unfortunately I can't just dremel it out; would destroy PCB traces.

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

hallard, 2022-11-25:
Dear @marcelstoer thanks for pointing that out, it's PI 4?

marcelstoer, 2022-11-25:
Sorry to mention that. Yes, for the Pi 4 they swapped the position of the outer USB-tower and the Ethernet connector.

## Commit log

2016-07-27 Routing Overlap fix
    [RPI-Lora-Gateway-Shield.brd]
2016-08-12 Added pictures of final board
2016-10-17 Bump to Version 1.1
    [RPI-Lora-Gateway-Shield.GBL, RPI-Lora-Gateway-Shield.GBO, RPI-Lora-Gateway-Shield.GBP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]
2016-11-15 Updated BOM and picture for V1.1
2016-11-15 Minor Silk and Trace Fix
    [RPI-Lora-Gateway-Shield.brd]
2016-12-08 Updated BOM
2016-12-08 Added standoff
2017-06-25 Bump to V1.2
    [RPI-Lora-Gateway-Shield.brd, RPI-Lora-Gateway-Shield.sch]
2017-06-25 Changed DC DC 5V vrong Link

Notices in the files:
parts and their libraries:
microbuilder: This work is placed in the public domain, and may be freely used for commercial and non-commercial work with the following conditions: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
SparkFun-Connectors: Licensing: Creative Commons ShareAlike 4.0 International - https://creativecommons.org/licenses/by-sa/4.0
